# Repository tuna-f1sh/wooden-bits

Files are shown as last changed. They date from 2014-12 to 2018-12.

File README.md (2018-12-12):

```
01000010 01101001 01101110 01100001 01110010 01111001  01000011 01101100 01101111 01100011 01101011
______ _                          _____ _            _    
| ___ (_)                        /  __ \ |          | |   
| |_/ /_ _ __   __ _ _ __ _   _  | /  \/ | ___   ___| | __
| ___ \ | '_ \ / _` | '__| | | | | |   | |/ _ \ / __| |/ /
| |_/ / | | | | (_| | |  | |_| | | \__/\ | (_) | (__|   < 
\____/|_|_| |_|\__,_|_|   \__, |  \____/_|\___/ \___|_|\_\
                           __/ |                          
                          |___/                           
```

# Binary Clock

Wooden Bits

Originally made for Arduino controller in my [*Wooden Bits*](http://wp.me/p2C0Bi-7R) project, this is a
binary clock for WS2812 LEDS that scales to any size pixel matrix. It includes
a function for generating the 'snakes and ladders' arrangment of pixels, which
can be used as a map reference for other functions.

## Features

* Version for Arduino/Atmega328 and Raspberry Pi.
* Scales to any size WS2812 matrix.
* Ability to rotate display.
* Ability to set second indicator pulsing.
* Quarter hour indicator fills n/quarter rows of the display blue (n is the
  quater multiple).
* Full rainbow at midday and midnight.
* `setMatrix` for sending any binary size to display; not just time.
* `initMatrixMap` for creating lookup map of disaply.

For more details, see my blog post: http://wp.me/p2C0Bi-7R

## Buy One!

[My Shop](https://shop.jbrengineering.co.uk/product/wooden-bits-binary-wall-clock/)
[Etsy](https://www.etsy.com/uk/listing/224396022/wooden-bits-laser-cut-wooden-binary)

## Requirements

### Hardware

* Arduino/atmega328 or Raspberry Pi.
* Pixel grid, user created or Adafruit NeoPixel, Pimoroni Unicorn Hat. Should
  be connected to pin 6 on Arduino or pin 18 on rPi by default.
* For Arduino you'll need a DS1307RTC/DS3231RTC chip, already set with the time (see
  library page).
* There is a KiCAD PCB project, which is what I now use for clocks I sell.

### Arduino Libraries  

* **Adafruit NeoPixel:** https://github.com/adafruit/Adafruit_NeoPixel
* **DS1307RTC RTC:** https://www.pjrc.com/teensy/td_libs_DS1307RTC.html

## Build

### Arduino

Compile using the Arduino IDE or using the Makefile. Using the makefile reqruies 'Arduino.mk':
https://github.com/sudar/Arduino-Makefile

Set the number of pixels in each row and column in 'bClock.h'. The clock will automatically scale
the binary bits to the pixel grid - thanks to the pixelMap generation.

You can defined a flash on seconds 'pulse_second', rotated display 'rotate' and brightness

### Raspberry Pi

Wooden Bits

Compile using `make` then run `sudo ./bClock [brightness] [pulse_second] [rotate]`. Designed for Raspberry Pi
and Pimoroni Unicorn Hat but code can scale to any size matrix. `pixelMap` generator is useful for 
other functions other than this code.

### Open SCAD

Compile within Open SCAD and export as .dxf. The comments explain how to
export the various different layout options. The designs are supplied for personal
use only under Creative Commons Attribution-NonCommercial 4.0 International
License.

## References

* **Adafruit NeoPixel library:** https://github.com/adafruit/Adafruit_NeoPixel
* **Unicorn Hat Driver:** https://github.com/pimoroni/UnicornHat/tree/master/c/unicorn
* **WS2812 Driver:** https://github.com/626Pilot/RaspberryPi-NeoPixel-WS2812

John Whittington [@j_whittington](http://www.twitter.com/j_whittington) http://www.jbrengineering.co.uk 2014

# Attribution and License



**Software** is 

**Hardware (KiCad, OpenSCAD, design exports etc.)** is 

I make many of my projects Open Source so others can learn as I have, but
please remember to follow the license terms and attribute any derivations or
code reuse. You can do this by linking back to the project or
[jbrengineering.co.uk](www.jbrengineering.co.uk). Feel free to click the
donate button above if you do use the source :).

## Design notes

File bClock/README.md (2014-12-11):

```
01000010 01101001 01101110 01100001 01110010 01111001  01000011 01101100 01101111 01100011 01101011
______ _                          _____ _            _    
| ___ (_)                        /  __ \ |          | |   
| |_/ /_ _ __   __ _ _ __ _   _  | /  \/ | ___   ___| | __
| ___ \ | '_ \ / _` | '__| | | | | |   | |/ _ \ / __| |/ /
| |_/ / | | | | (_| | |  | |_| | | \__/\ | (_) | (__|   < 
\____/|_|_| |_|\__,_|_|   \__, |  \____/_|\___/ \___|_|\_\
                           __/ |                          
                          |___/                           
```

# Binary Clock

Wooden Bits

Originally made for Arduino controller in my [*Wooden Bits*](http://wp.me/p2C0Bi-7R) project, this is a
binary clock for WS2812 LEDS that scales to any size pixel matrix. It includes
a function for generating the 'snakes and ladders' arrangment of pixels, which
can be used as a map reference for other functions.

## Features

* Version for Arduino/Attiny328 and Raspberry Pi.
* Scales to any size WS2812 matrix.
* Ability to rotate display.
* Ability to set second indicator pulsing.
* Quarter hour indicator fills n/quarter rows of the display blue (n is the
  quater multiple).
* Full rainbow at midday and midnight.
* `setMatrix` for sending any binary size to display; not just time.
* `initMatrixMap` for creating lookup map of disaply.

For more details, see my blog post: http://wp.me/p2C0Bi-7R

You also drive a Unicorn Hat with it:

Unicorn Hat Driven by Arduino

## Requirements

### Hardware

* Arduino/attiny328 or Raspberry Pi.
* Pixel grid, user created or Adafruit NeoPixel, Pimoroni Unicorn Hat. Should
  be connected to pin 6 on Arduino or pin 18 on rPi by default.
* For Arduino you'll need a DS1307RTC chip, already set with the time (see
  library page).

### Arduino Libraries  

* **Adafruit NeoPixel:** https://github.com/adafruit/Adafruit_NeoPixel
* **DS1307RTC RTC:** https://www.pjrc.com/teensy/td_libs_DS1307RTC.html

## Build

### Arduino

Compile using the Arduino IDE or using the Makefile. Using the makefile reqruies 'Arduino.mk':
https://github.com/sudar/Arduino-Makefile

Set the number of pixels in each row and column in 'bClock.h'. The clock will automatically scale
the binary bits to the pixel grid - thanks to the pixelMap generation.

You can defined a flash on seconds 'pulse_second', rotated display 'rotate' and brightness

## References

* **Adafruit NeoPixel library:** https://github.com/adafruit/Adafruit_NeoPixel
* **Unicorn Hat Driver:** https://github.com/pimoroni/UnicornHat/tree/master/c/unicorn
* **WS2812 Driver:** https://github.com/626Pilot/RaspberryPi-NeoPixel-WS2812

John Whittington [@j_whittington](http://www.twitter.com/j_whittington) http://www.jbrengineering.co.uk 2014

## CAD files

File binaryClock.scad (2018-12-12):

// Wooden Bits by John Whittington - www.jbrengineering.co.uk
// http://engineer.john-whittington.co.uk/2014/12/wooden-bits-binary-clock/
//
// This work is licensed under the Creative Commons Attribution-ShareAlike 4.0 International License. To view a copy of this license, visit http://creativecommons.org/licenses/by-sa/4.0/// 
// Please include this header with any modification.

// Laser cutter beam kerf
LaserBeamDiameter = 0.23;

// Material characteristic
materialThickness = 3.20;    // Material thickness
// TODO Plastic thickness

// Objects dimensions and other settings
depth = 50; // depth of matrix
hLights = 4; // number of horizontal lights (rows)
vLights = 4; // number of vertical lights (columns)
lightHeight = 50; // height of each light box
lightWidth = 50; // width of each light box
screw_r = 2;
screw_cap = 3.6;
power_r = 4;
button_r = 2.5;
wire_r = 6;

// --- kerf bend ----
slotLength = 15;
slotWidth = 0.5;
slotDistance = 2; // distance between
slots = depth/slotLength;

// dividers slot
slotDividerLength = 10;
// diffuser slot
dentLength = 10;

// --- working ----
// get the parameter of the curve (half)
parameterCurve = PI*(lightHeight/2)+materialThickness*2;
// length of section top/bottom
lengthSection = ((hLights+1)*materialThickness)+(hLights*lightWidth);
// length of section containing lights
sepLight = lengthSection/hLights;

// --- EXPORT SETTIGS --- 
split = 1; // divide complete strip by this number
spacing = 1; // spacing between cut outs
middle = 0; // whether to make cable holes on top and bottom for middle sections
$fn=100;

// overall length of sheet
/* lengthSheet = (vLights*parameterCurve)+((vLights+1)*(lengthSection+materialThickness))+LaserBeamDiameter; // uncomment for one-piece*/
/* single = 0;*/

// !! comment out for one piece
lengthSheet = parameterCurve+lengthSection*2+LaserBeamDiameter+materialThickness*2; // comment out for one piece
single = 1;

echo("Area Wood:");
echo(( (spacing+lengthSheet)*4 )*((spacing+materialThickness+lightHeight)*4));
echo("Acrylic Area:");
echo((4*( lightHeight+spacing ))*(4*(lightWidth+spacing)));

// comment uncomment for different dxf exports to cut wood sections of acrylic diffusers
/* fullPrint();*/
/* acrylic();*/
/* wood();*/
/* fullWood(); */
/* screwPlate();*/
lightDivider(2);
/* pcb_holder(); */

// --- END EXPORT ---

module body(middle)
{
difference() {
  // make the base sheet
  square([lengthSheet/split, depth]);
  // we're splitting the sheet
  translate([materialThickness/2,0]) { // end section adds material
    if (single == 0) {
        for (z = [1 : hLights/split]) {
          // move along the y (depth) creating columns of slots (depth * 2 to make sure we make it over)
          for (x = [0 : slotLength+slotDistance : depth*2]) {
            slotColumn((lengthSection+materialThickness)*z+(parameterCurve*(z-1)),x);
            slotColumn((lengthSection+materialThickness)*z+slotDistance+(parameterCurve*(z-1)),x+slotLength/2);
          };
        };
    } else { // one block (top bottom and curve)
        // move along the y (depth) creating columns of slots (depth * 2 to make sure we make it over)
        for (x = [0 : slotLength+slotDistance : depth*2]) {
          slotColumn(lengthSection*1+materialThickness,x);
          slotColumn(lengthSection*1+slotDistance+materialThickness,x+slotLength/2);
        };
    };
    if (middle == 1) {
      for (x = [0:3]) { // cable holes at both ends
        translate([sepLight/2+((lengthSection+parameterCurve+materialThickness)*x),depth-10]) circle(wire_r,center=true);
        translate([lengthSection-sepLight/2+((lengthSection+parameterCurve+materialThickness)*x),depth-10]) circle(wire_r,center=true);
        // cut ends off middle sections
        /* translate([-materialThickness/2,0]) square([(lengthSection/2+materialThickness/2), depth]);*/
        /* translate([-materialThickness/2+lengthSection*1.5+parameterCurve+materialThickness*1.5,0]) square([(lengthSection/2+materialThickness/2+LaserBeamDiameter), depth]);*/
      }
    } else if (middle == 2) { // cable holes near curve only
        translate([sepLight/2,depth-10]) circle(wire_r,center=true);
    } else { // cable holes near curve only
        translate([lengthSection-sepLight/2,depth-10]) circle(wire_r,center=true);
    }
  }
  // add a slot at the end for end blanking
  translate([materialThickness/2-LaserBeamDiameter,0])slotDivider();
  // add slots along the number of lights
  translate([materialThickness/2,0]) {
    for (z = [0:vLights/split]) {
      for (x = [0:hLights]) {
        translate([(sepLight*x)+((lengthSection+parameterCurve+materialThickness)*z),0]) slotDivider();
      };
    };
    // alternate dents
    for (z = [0:2:vLights/split]) {
      translate([(lengthSection+parameterCurve+materialThickness)*z,0]) {
        for (x = [0:hLights-1]) {
          translate([sepLight*x,0]) dentB();
          translate([sepLight*x,depth-materialThickness]) dentB();
        };
      };
    };
    for (z = [1:2:vLights/split]) {
      translate([(lengthSection+parameterCurve+materialThickness)*z,0]) {
        for (x = [0:hLights-1]) {
          translate([sepLight*x,depth-materialThickness]) dentB();
          translate([sepLight*x,0]) dentB();
        };
      };
    };
  };
};
};

module fullPrint() {
body(middle);
translate([materialThickness,0]) {
  for (x = [0:hLights]) {
    // we don't want a cable run at the end piece
    if (x < hLights - 2) {
      translate([x*(lightHeight+materialThickness*2+spacing*2),depth+spacing]) lightDivider(1);
    } else {
      translate([x*(lightHeight+materialThickness*2+spacing*2),depth+spacing]) lightDivider(0);
    }
  };
};
/* translate([materialThickness+lengthSection+parameterCurve,-220]) {*/
  translate([0,depth*2+lightHeight+materialThickness*2+LaserBeamDiameter+spacing*3]) backingPlate();
  for (x = [0:hLights-1]) {
    translate([(sepLight)*x,depth*2+spacing*2]) lightDiffuser();
  };
/* };*/
};

module acrylic() {
  hAcrylic = 500;
  wAcrylic = 800;
  for (y = [0:lightHeight+LaserBeamDiameter+materialThickness*2+spacing:wAcrylic-lightHeight]) {
    for (x = [0:lightWidth+LaserBeamDiameter+spacing:hAcrylic-lightWidth]) {
      translate([x,y]) lightDiffuser();
    }
  }
}

module wood(mid) {
body(mid);
translate([materialThickness,0]) {
  for (x = [0:hLights]) {
    // we don't want a cable run at the end piece
    if (x < hLights - 1) {
      translate([x*(lightHeight+materialThickness*2+spacing*2),depth+spacing]) lightDivider(1);
    } else {
      if ((mid == 0) && (x == 4)) {
        translate([x*(lightHeight+materialThickness*2+spacing*2),depth+spacing]) lightDivider(2);
      } else {
        translate([x*(lightHeight+materialThickness*2+spacing*2),depth+spacing]) lightDivider(0);
      }
    }
  };
};
/* translate([materialThickness+lengthSection+parameterCurve,-220]) {*/
  if (mid == 0) {
    translate([(hLights+1)*(lightHeight+materialThickness*2+spacing*2),depth*1+spacing*1+materialThickness]) backingPlate(1);
  } else {
  translate([(hLights+1)*(lightHeight+materialThickness*2+spacing*2),depth*1+spacing*1+materialThickness]) backingPlate(0);
  }
/* };*/
}

module screwPlate() {
  backingPlate(1);
}

module fullWood() {
  for (x = [0:3]) {
    if (x <= 1) {
      translate([0,(depth*2+spacing*3+materialThickness*2)*x]) wood(1);
    } else if (x == 2) {
      translate([0,(depth*2+spacing*3+materialThickness*2)*x]) wood(2);
    } else {
      translate([0,(depth*2+spacing*3+materialThickness*2)*x]) wood(0);
    }
  }
}

// makes column of slots (x direction)
module slotColumn(xpos,ypos)
{
  for (i = [0 : slotDistance*2 : parameterCurve-slotDistance]) {
    translate([xpos+i,ypos]) {
      square([slotWidth-LaserBeamDiameter,slotLength-LaserBeamDiameter],center=true);
    }
  }
}

// makes a pair of slots for light dividers
module slotDivider()
{
  translate([0,depth/2-depth/4]) square([materialThickness-LaserBeamDiameter,slotDividerLength-LaserBeamDiameter],center=true);
  translate([0,depth/2+depth/4]) square([materialThickness-LaserBeamDiameter,slotDividerLength-LaserBeamDiameter],center=true);
}

module dentA()
{
  translate([sepLight/2,materialThickness/2]) square([dentLength-LaserBeamDiameter,materialThickness],center=true);
}

module dentB()
{
  translate([sepLight/4,materialThickness/2]) {
    square([dentLength-LaserBeamDiameter,materialThickness],center=true);
    translate([sepLight/2,0]) square([dentLength-LaserBeamDiameter,materialThickness],center=true);
  }
}

module toothB()
  translate([sepLight/4,-materialThickness/2]) {
    square([dentLength+LaserBeamDiameter,materialThickness],center=true);
    translate([sepLight/2,0]) square([dentLength+LaserBeamDiameter,materialThickness],center=true);
  }
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

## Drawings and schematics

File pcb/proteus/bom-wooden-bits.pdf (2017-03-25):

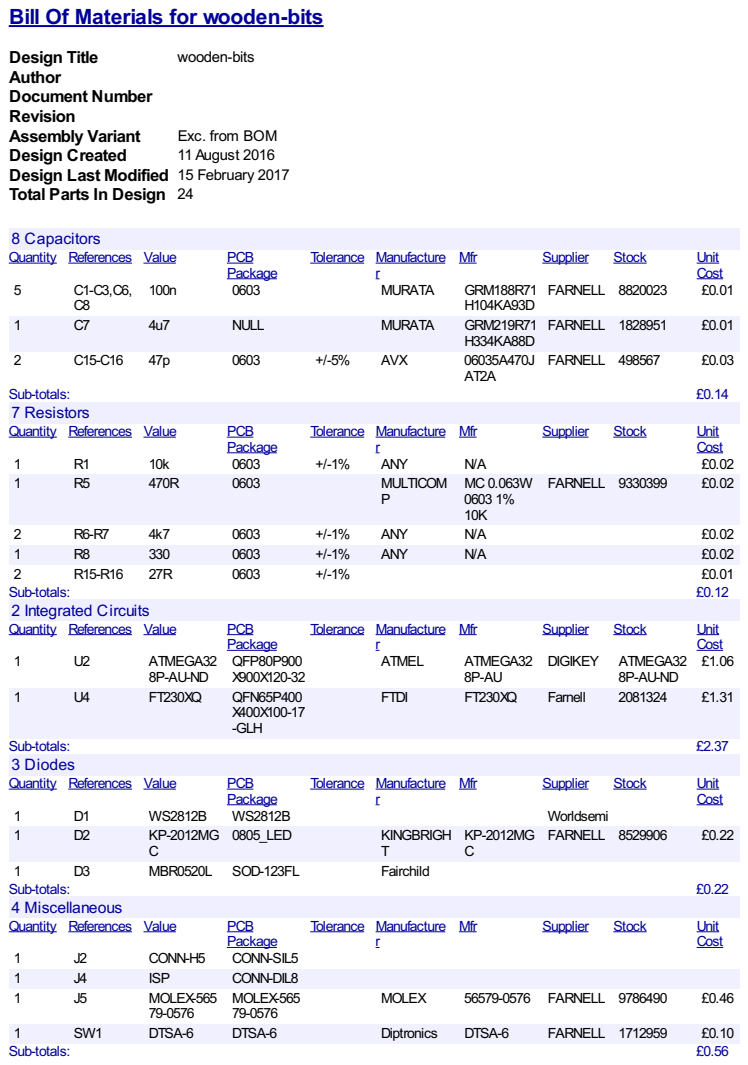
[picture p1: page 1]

Bill Of Materials for wooden-bits

Author
Document Number
Revision
Design Last Modified 15 February 2017
Total Parts In Design 24

1 | R5 | 470R | 0603 | MULTICOM | MC0.063W | FARNELL | 9330399 | £0.02

1 | D2 | KP-2012MG | 0805_LED | KINGBRIGH | KP-2012MG | FARNELL | 8529906 | £0.22

Tot

als: | £
| 3.4

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
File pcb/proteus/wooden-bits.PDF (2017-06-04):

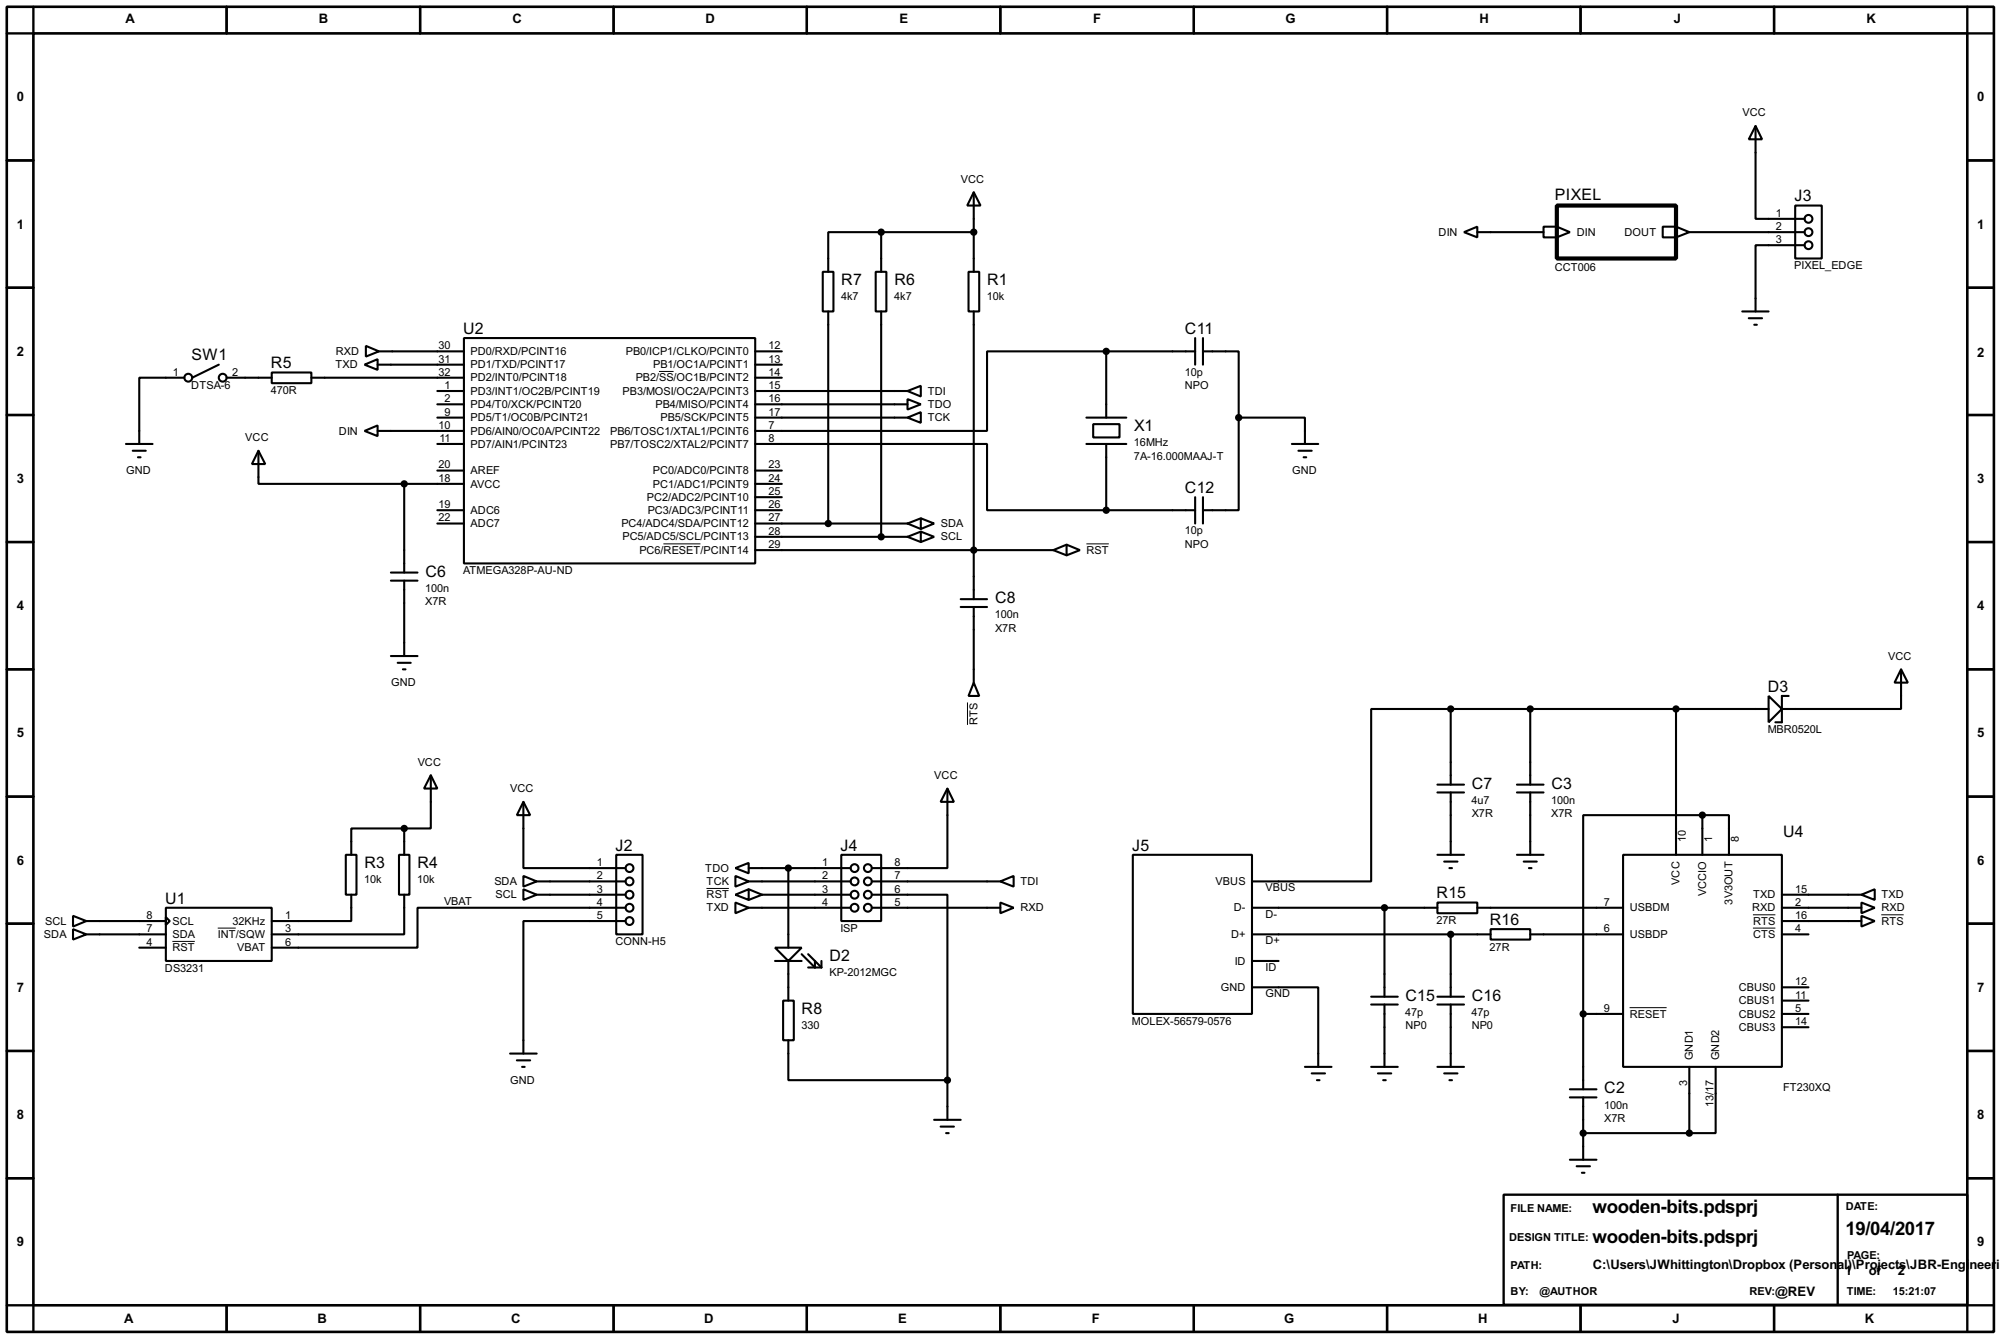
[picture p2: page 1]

TDI TCK TDO

16 PB5/SCK/PCINT5

17 PB7/TOSC2/XTAL2/PCINT7 7
8 PB6/TOSC1/XTAL1/PCINT6

PAGE: wooden-bits.pdsprj

FILE NAME:
DESIGN TITLE: wooden-bits.pdsprj

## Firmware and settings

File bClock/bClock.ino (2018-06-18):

/*
===================================================================================================

01000010 01101001 01101110 01100001 01110010 01111001  01000011 01101100 01101111 01100011 01101011
______ _                          _____ _            _    
| ___ (_)                        /  __ \ |          | |   
| |_/ /_ _ __   __ _ _ __ _   _  | /  \/ | ___   ___| | __
| ___ \ | '_ \ / _` | '__| | | | | |   | |/ _ \ / __| |/ /
| |_/ / | | | | (_| | |  | |_| | | \__/\ | (_) | (__|   < 
\____/|_|_| |_|\__,_|_|   \__, |  \____/_|\___/ \___|_|\_\
                           __/ |                          
                          |___/                           

 Binary Clock
 Originally made for Arduino controller in my 'Wooden Bits' project
 John Whittington @j_whittington http://www.jbrengineering.co.uk 2014

 Compile using the Arduino IDE or using the Makefile. Using the makefile reqruies 'Arduino.mk':
 https://github.com/sudar/Arduino-Makefile
 "
 Set the number of pixels in each row and column in 'bClock.h'. The clock will automatically scale
 the binary bits to the pixel grid - thanks to the pixelMap generation.
 
 You can defined a flash on seconds 'pulse_second', rotated display 'rotate' and brightness

 Arduino Libraries - Adafruit NeoPixel: https://github.com/adafruit/Adafruit_NeoPixel
                     DS1307RTC RTC: https://www.pjrc.com/teensy/td_libs_DS1307RTC.html

 References - Adafruit NeoPixel library: https://github.com/adafruit/Adafruit_NeoPixel

===================================================================================================
*/

#include <Wire.h>
#include <TimeLib.h>
#include <Adafruit_NeoPixel.h>
#include "bClock.h"

#ifdef CHIP_DS3232RTC
  #include <DS3232RTC.h>
  #define RTC_RETURN 0
#elif defined CHIP_DS1307RTC
  #include <DS1307RTC.h>
  #define RTC_RETURN 0
#endif

 /* ---- CONFIGURE ---- */
/*==========================*/

// delay for startup wipe
#define WIPE_DELAY     50
// delay for quarter hour display
#define QUARTER_WAIT   15000
// number of pixels (row and column are defined in header)
#define NUMPIXELS PIXEL_ROW*PIXEL_COLUMN
// Width and height of square to show bit
const static uint8_t width = PIXEL_ROW/4;
const static uint8_t height = PIXEL_COLUMN/4;
// Cordinate map of pixel init (gets filled by initMatrixMap)
uint16_t pixelMap [PIXEL_ROW][PIXEL_COLUMN] = {{0}};
// pulse at second intervals
const static uint8_t pulse_second = false;
// rotate the grid 90deg?
const static uint8_t rotate = false;
// brightness (0 darkest (off) - 255 retina searing)
const static uint8_t brightness = 255;
// set time flag from ISR
static uint8_t flag = false;
static uint8_t set_clock = false;
static uint8_t set_colour = false;

// When we setup the NeoPixel library, we tell it how many pixels, and which pin to use to send signals.
// Note that for older NeoPixel strips you might need to change the third parameter--see the strandtest
// example for more information on possible values.
Adafruit_NeoPixel pixels = Adafruit_NeoPixel(NUMPIXELS, PIN, NEO_GRB + NEO_KHZ800);

static uint32_t main_colour;
static uint32_t quarter_colour = pixels.Color(0,0,255);

/* ---- SETUP ---- */
/*=====================*/

static void setISR(void) {
  static unsigned long last_interrupt_time = 0;
  unsigned long interrupt_time = millis();

  // disable interrupts until acted on
  noInterrupts();

  // debouce
  if (interrupt_time - last_interrupt_time > 200)
    flag = true;
  else
    interrupts();

  last_interrupt_time = interrupt_time;
}

static void processISR(void) {
  uint32_t hold = millis();

  while (!digitalRead(2) && !set_colour) {
    if (millis() - hold < 5000) {
      set_clock = true;
    } else if (!digitalRead(2)) {
      set_clock = false;
      set_colour = true;
    }
  }
}

static void setColour(void) {
  uint32_t entry = millis(); // entry time - reset each button press
  uint32_t debouce = 0;
  uint8_t ci = 0;
  
  pixels.clear();

  while(millis() - entry < 5000) {
    if (!digitalRead(2)) {
      if ((millis() - debouce) > 10) {
        entry = millis();

        main_colour = Wheel(ci);
        ci = (ci++ <= 255) ? ci : 0;
        for (uint16_t i=0;i<NUMPIXELS;i++) {
          pixels.setPixelColor(i, main_colour);
        }
        pixels.show();

        debouce = millis();
      }
    }
  }

  flag = false;
  set_colour = false;
  interrupts();
}

void setup() {
  byte bVersion[4] = {B0000};

  attachInterrupt(0, setISR, FALLING);
  // pull-up interrupt
  pinMode(2,INPUT_PULLUP);

  Serial.begin(9600);
  while (!Serial) ; // wait for serial
  pixels.begin(); // This initializes the NeoPixel library.

  // Create the matrix lookup map
  initMatrixMap(pixelMap,rotate);

  pixels.setBrightness(brightness);
  main_colour = pixels.Color(255,255,255);

  // Show software version at boot
  bVersion[3] = VERSION_MINOR;
  bVersion[2] = VERSION_MAJOR;
  setMatrix(bVersion, sizeof(bVersion)/sizeof(bVersion[1]), main_colour, pixels.Color(255,0,0));
  delay(2000);

  // wipe through rgb for LED debug
  colorWipe(pixels.Color(255,0,0),WIPE_DELAY);
  colorWipe(pixels.Color(0,255,0),WIPE_DELAY);
  colorWipe(pixels.Color(0,0,255),WIPE_DELAY);
  colorWipe(pixels.Color(0,0,0),WIPE_DELAY);
}

/* ---- LOOP ---- */
/*====================*/

void loop() {
  static tmElements_t tm; // time struct holder
  static uint32_t setDelay = 0;
  // nyble vector for matrix columns
  // [hour/10, hour/1, minute/10, minute/1]
  byte bTime[4] = {B0000};

  // Process interrupt button call
  if (flag) {
    processISR();
    if (set_clock) {
      setBClock(tm, bTime, sizeof(bTime));
    } else if (set_colour) {
      setColour();
    }
  }
  
  // Set clock every 1s
  if ((millis() - setDelay) >= 1000) {
    // wait a second before checking the time again
    setDelay = millis();

    // get the time from RTC
    if (RTC.read(tm) == RTC_RETURN) {
    } else {
      // rtc isn't reading
      Serial.println("RTC read error!  Please check the circuitry.");
      Serial.println();
      solidColor(255,0,0); // all red
      // error loop: wait 9s then try again
      delay(9000);
      return;
    }

    // convert the time to nybles for the matrix
    pixelTime(tm, bTime);

    // quarter hour indicator
    if ( (tm.Minute % 15 == 0) && (tm.Second == 0) ) {
      quarterHour(tm.Hour, tm.Minute, QUARTER_WAIT);
    }
    // turn them all off for second indicator flash
    if (pulse_second) {
      for (uint8_t x = 0; x < PIXEL_ROW; x += width) {
        for (uint8_t y  = 0; y < PIXEL_COLUMN; y += height) {
          setPixel(pixelMap[x][y], 1, pixels.Color(0,0,0));
        }
      }
      pixels.show();
      delay(10);
    }
    // set the matrix to the binary time
    setMatrix(bTime, sizeof(bTime)/sizeof(bTime[1]), main_colour, pixels.Color(255,0,0));
  }
}

 /* ---- CLOCK FUNCTIONS ----*/
/*===============================*/

// fills the binary array with nybles
void pixelTime(tmElements_t tm, byte *bTime) {
  // convert the hour and minute into uint8
  uint8_t hour = tm.Hour;
  uint8_t minute = tm.Minute;

  // convert the time into 4 nybles for each column of matrix
  if (hour >=0 && hour < 10) {
    bTime[1] = hour | B0000;
    bTime[0] = B0000; // 2nd digit still needs clearing
  } else {
    bTime[1] = uint8_t (hour-(floor(hour/10)*10)) | B0000;
    bTime[0] = uint8_t ((hour-(hour-floor(hour)))/10) | B0000;
  }
  if (minute >=0 && minute < 10) {
    bTime[3] = minute | B0000;
    bTime[2] = B0000; // 2nd digit still needs clearing
  } else {
    bTime[3] = uint8_t (minute-(floor(minute/10)*10)) | B0000;
    bTime[2] = uint8_t ((minute-(minute-floor(minute)))/10) | B0000;
  }
}

// fills multiples 1/4 of matrix for 1/4 hour multiple
void quarterHour(uint8_t hour, uint8_t minute, uint16_t wait) {
  uint8_t no_rows;
  uint8_t y;
  uint8_t x;
  int16_t j;
  uint32_t wait_ms = 0;
  // light number of rows depending on the hour quarter (floored to be safe)
  no_rows = floor(minute / 15) * height;
  // one hour indicator is actually 0 but we want full display
  no_rows = (no_rows == 0) ? (4 * height) : no_rows;

  solidColor(0,0,0); // turn them all off
  pixels.show();

  if ((hour == 12 || hour == 0 ) && minute == 0) {
    rainbowCycle(48); // special edition hour for midday (46 will cycle for just over 1 min 1280*48)
  } else { // fade columns in and out

    hour = ((minute == 0) && (hour > 0)) ? (hour - 1) : hour; // full display should be colour of previous hour
    quarter_colour = Wheel(map(hour,0,23,0,255));

    for (j = 0; j <= 255; j += 5) {
      for (y = 0; y < no_rows; y++) {
        for (x = 0; x < PIXEL_ROW; x++) {
        setPixel(pixelMap[x][y],1,quarter_colour);
        pixels.setBrightness(j);
        }
      }
      pixels.show();
      delay(10);
    }
    wait_ms = millis();
    while ( ((millis() - wait_ms) < wait) && !flag );; // hold on with dirty escape with ISR
    for (j = 255; j >= 0; j -= 5) {
      for (y = 0; y < no_rows; y++) {
        for (x = 0; x < PIXEL_ROW; x++) {
        setPixel(pixelMap[x][y],1,quarter_colour);
        pixels.setBrightness(j);
        }
      }
      pixels.show();
      delay(10);
    }

    // reset brightness on way out
    pixels.setBrightness(brightness);
  }
}

// sets the binary array to the matrix columns
void setMatrix(byte bMatrix[], size_t size, uint32_t color1, uint32_t color2) {
  uint8_t x; // row inc.
  uint8_t y; // height inc.
  uint8_t i; // binary set matrix
  uint8_t yy; // full column inc.
  uint8_t xx = 0; // full row inc.

  for ( i = 0; i < size; i++) {
    for (yy = 0;yy < PIXEL_COLUMN; yy += height) {
      for (y = 0; y < height; y++) {
        for (x = 0; x < width; x++) {
          if (x == 0 && y == 0) {
            setPixel(pixelMap[xx+x][yy+y],((bMatrix[i] >> yy/height) & 1),color1);
          } else {
            setPixel(pixelMap[xx+x][yy+y],((bMatrix[i] >> yy/height) & 1),color2);
          }
        }
      }
    }
    xx += width;
  }
  pixels.show();
}

// creates a cordinate map of pixels in the matrix
void initMatrixMap(uint16_t pixelMap[PIXEL_ROW][PIXEL_COLUMN], uint8_t rotate) {
  uint8_t i; // row inc.
  uint8_t j; // column inc.
  uint16_t pixel_inc; // pixel number inc.

  /* What we're trying to draw (64 pixel unicorn hat grid) */
  /* It's a snakes and ladders type arrangement for any matrix */
  /*   {7 ,6 ,5 ,4 ,3 ,2 ,1 ,0 },*/
  /*   {8 ,9 ,10,11,12,13,14,15},*/
  /*   {23,22,21,20,19,18,17,16},*/
  /*   {24,25,26,27,28,29,30,31},*/
  /*   {39,38,37,36,35,34,33,32},*/
  /*   {40,41,42,43,44,45,46,47},*/
  /*   {55,54,53,52,51,50,49,48},*/
  /*   {56,57,58,59,60,61,62,63}*/
  /* */

  // The cord either starts at 0 or length of row depending on whether it's rotated
  pixel_inc = rotate ? PIXEL_ROW : 0;

  for (i = 0; i < PIXEL_COLUMN; i++) {
    for (j = 0; j < PIXEL_ROW; j++) {
      // We either increment or decrement depending on column due to snakes and ladders arrangement
      if (rotate) {
        pixelMap[i][j] = (i % 2 == 0) ? --pixel_inc : ++pixel_inc;
      } else {
        pixelMap[j][i] = (i % 2 != 0) ? pixel_inc-- : pixel_inc++;
      }
    }
    pixel_inc += PIXEL_ROW;
    (i % 2 == 0) ? pixel_inc-- : pixel_inc++;
  }
}

void setBClock(tmElements_t &tm, byte *bTime, uint8_t size) {
  uint32_t entry = millis(); // entry time - reset each button press
  uint32_t hold = millis(); // hold timer to increase time change
  uint32_t debounce = 0; // debouce holder
  uint8_t dperiod = 200; // debouce period
  uint8_t state; // button state

  // run for 5s then save the time to RTC
  while (millis() - entry < 5000) {

    // set the matrix to the binary time for user to see curret setting
    pixels.clear();
    setMatrix(bTime, size/sizeof(bTime[1]), pixels.Color(255,0,0), pixels.Color(255,0,0));
    
    state = digitalRead(2);

    if (!state) {

      if (millis() - hold > 1000) {
        dperiod = 20;
      } else {
        dperiod = 200;
      }

      if ((millis() - debounce) > dperiod ) {
        entry = millis();

        tm.Minute++;

        if (tm.Minute == 60) {
          tm.Hour++;
          tm.Minute = 0;
          if (tm.Hour == 24) {
            tm.Hour = 0;
          }
        }

        debounce = entry;
      }

    } else {
      hold = millis(); // reset the hold button as hasn't been pressed
    }

    pixelTime(tm, bTime);
  }

  // save to RTC, clear ISR flag and resume interrupts
  RTC.write(tm);
  flag = false;
  interrupts();

}

// set the matrix to a solid colour
void solidColor(uint32_t r,uint32_t g,uint32_t b) {
  for (uint16_t i=0;i<NUMPIXELS;i++) {
    pixels.setPixelColor(i, pixels.Color(r,g,b));
  }
  pixels.show();
}

// set the pixel on or off
void setPixel(uint8_t pixel, uint8_t set, uint32_t c) {
  if (set) {
    pixels.setPixelColor(pixel, c);
  } else {
    pixels.setPixelColor(pixel, pixels.Color(0,0,0));
  }
}

 /* ---- ADAFRUIT NEOPIXEL FUNCTIONS ---- */
/*============================================*/

// Fill the dots one after the other with a color (Adafruit)
void colorWipe(uint32_t c, uint8_t wait) {
  for(uint16_t i=0; i<NUMPIXELS; i++) {
      pixels.setPixelColor(i, c);
      pixels.show();
      delay(wait);
  }
}

void rainbow(uint8_t wait) {
  uint16_t i, j;

  for(j=0; j<256; j++) {
    for(i=0; i<pixels.numPixels(); i++) {
      pixels.setPixelColor(i, Wheel((i+j) & 255));
    }
    pixels.show();
    delay(wait);
  }
}

// Slightly different, this makes the rainbow equally distributed throughout
void rainbowCycle(uint8_t wait) {
  uint16_t i, j;

  for(j=0; j<256*5; j++) { // 5 cycles of all colors on wheel
    for(i=0; i< pixels.numPixels(); i++) {
      pixels.setPixelColor(i, Wheel(((i * 256 / pixels.numPixels()) + j) & 255));
    }
    pixels.show();
    // exit if button is pressed to allow acting on
    if (flag) {i = pixels.numPixels(); j = 256 * 5; }
    delay(wait);
  }
}

// Input a value 0 to 255 to get a color value.
// The colours are a transition r - g - b - back to r.
uint32_t Wheel(byte WheelPos) {
  WheelPos = 255 - WheelPos;
  if(WheelPos < 85) {
   return pixels.Color(255 - WheelPos * 3, 0, WheelPos * 3);
  } else if(WheelPos < 170) {
    WheelPos -= 85;
   return pixels.Color(0, WheelPos * 3, 255 - WheelPos * 3);
  } else {
   WheelPos -= 170;
   return pixels.Color(WheelPos * 3, 255 - WheelPos * 3, 0);
  }
}

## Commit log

2014-12-04 Changed code directory to bClock to allow Arduino IDE compilation
2014-12-07 Added port to Raspberry Pi and Unicorn Hat
2014-12-10 Tidied up/improved Arduino code from Raspberry Pi development
2014-12-11 Added Arduino driving Unicorn Hat to readme
2015-02-06 Added OpenSCAD source for creating print sheet
    [binaryClock.scad]
2015-02-06 Updated README and scad on license terms.
    [binaryClock.scad]
2015-02-24 Added clock setting routine via tactile button to Arduino code
2015-03-22 Added support for the more accurate RTC DS3232 and small openSCAD design export changes.
    [binaryClock.scad]
2015-11-14 Design file changes for wall mounting and DC adaptor@
    [binaryClock.scad]
2015-12-18 Removed cable run end piece. Moved top cable run to correct position
    [binaryClock.scad]
2016-06-29 Hold set button to set main colour, quick press to set clock
2016-08-11 PCB added with Arduino hardware config and bootloader
2016-08-11 Xtal footprint changed for hand soldering;10k and 4k7 DS3231 pull-ups DNF
2016-08-11 PCB revision incremented 1B
2016-09-20 Updated PCB panel for custom PCB
    [binaryClock.scad]
2016-10-01 Acrylic export size increased
    [binaryClock.scad]
2016-10-28 Micro usb for power input and bootloader fuses
    [binaryClock.scad]
2016-10-30 Wire hole radius parameterised and increased to 5mm
    [binaryClock.scad]
2016-11-04 PCB added mount holes and licence update software to GPL
2017-03-25 PCB exports
2017-06-04 Improved quarter hour display and possible rainbow mode
    [binaryClock.scad]
2017-08-24 Move button hole up 1mm
    [binaryClock.scad]
2017-11-29 Allow button to exit rainbow at start and midday
2017-12-04 Set wire run relief to match wire radius
    [binaryClock.scad]
2018-06-01 Fix quarter hour indicator repeating at 00:00 and 12:00
    [bClock.ino]
2018-06-18 Fix button press during quarter hour indicator
    [bClock.ino]
2018-08-20 Update to use Honock PCB
    [binaryClock.scad]
2018-12-12 Side panel for honock PCB and README updates
    [binaryClock.scad]

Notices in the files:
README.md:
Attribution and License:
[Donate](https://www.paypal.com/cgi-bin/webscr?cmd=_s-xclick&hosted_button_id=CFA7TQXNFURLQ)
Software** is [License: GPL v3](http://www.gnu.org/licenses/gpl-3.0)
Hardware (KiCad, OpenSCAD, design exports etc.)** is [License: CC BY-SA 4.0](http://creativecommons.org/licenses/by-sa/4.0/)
